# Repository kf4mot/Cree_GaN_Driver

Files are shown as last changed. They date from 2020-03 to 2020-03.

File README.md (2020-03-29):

# Cree GaN Gate Driver and Power Sequencer.
A general purpose GaN gate driver board based on [Cree APPNOTE-011 Rev. B](https://github.com/kf4mot/Cree_GaN_Driver/blob/master/docs/gan_hemt_biasing_circuit_with_temperature_compensation.pdf).
Provides about 2 ms of delay after power is good before switching on the mosfet. Switch off during power fail or shut down is nearly instant.

**Incomplete. Tested with DC load for function and power sequencing only.**

**Things worth knowing**

1. If operating at 14 Volts or less then R10 should be decreased from 4.7KΩ to 1KΩ.
1. C8 value can change per installation, or is optional. A though hole electrolytic soldered to the adjacent power pads is also a convenient option for bulk capacitance.
1. Infineon SPD15P10PL G can be used as a alternate mosfet. **Untested**
1. The series resistance that is R11, R13, and RV1 is there for hackability. Allowing for GaN's with differing gate voltage requirements and to have the ability to use fixed resistors for preventing voltage shift.

[Schematic](https://github.com/kf4mot/Cree_GaN_Driver/blob/master/hardware/Cree_GaN_Driver.pdf)

[Licensed under CERN-OHL-S V2. Julian White, 2020](https://www.ohwr.org/project/cernohl/wikis/home)

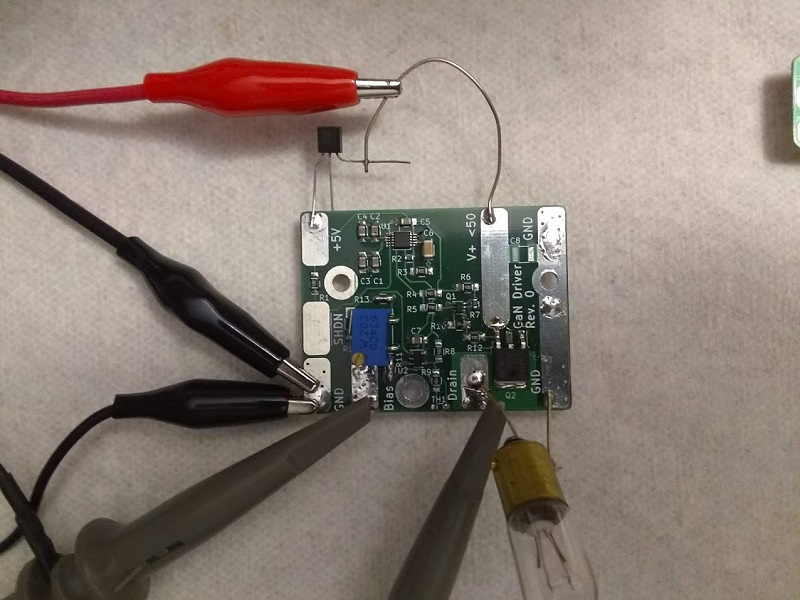
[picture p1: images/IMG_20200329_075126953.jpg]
First! First Board


Ch.1 is drain. Ch.2 is gate.

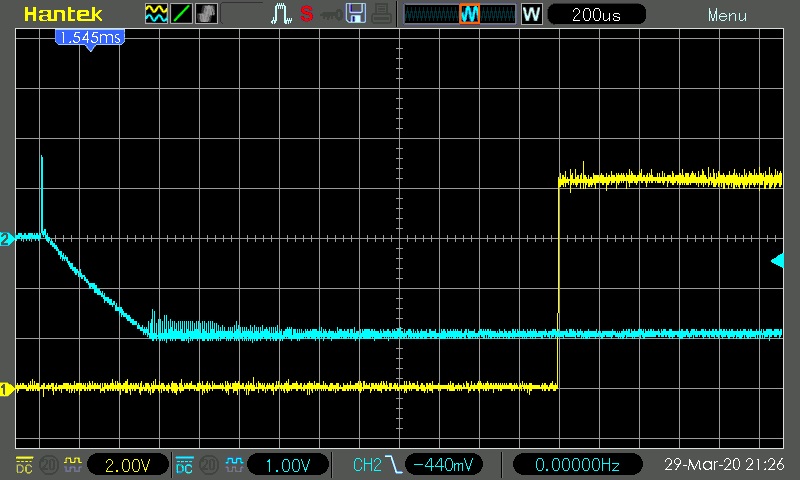
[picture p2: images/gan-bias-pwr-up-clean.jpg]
First! Normal Power Up


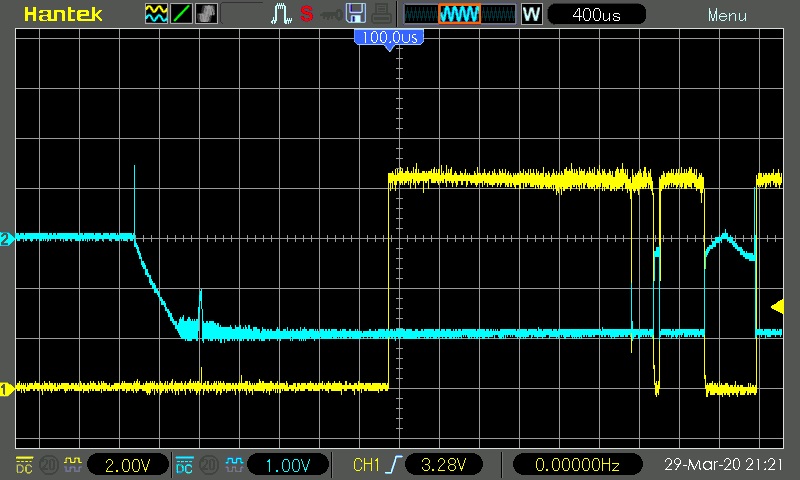
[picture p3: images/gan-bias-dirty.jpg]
First! Power Fail at Power Up


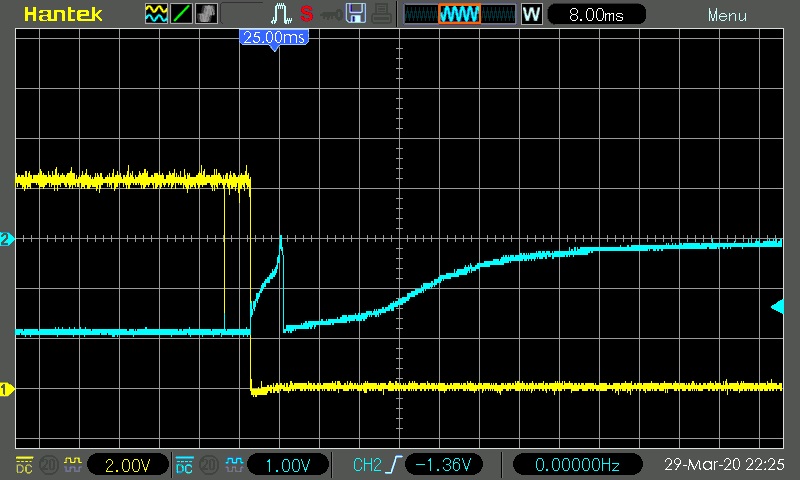
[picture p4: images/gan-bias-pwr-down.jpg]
What does this do? Normal Turn Off


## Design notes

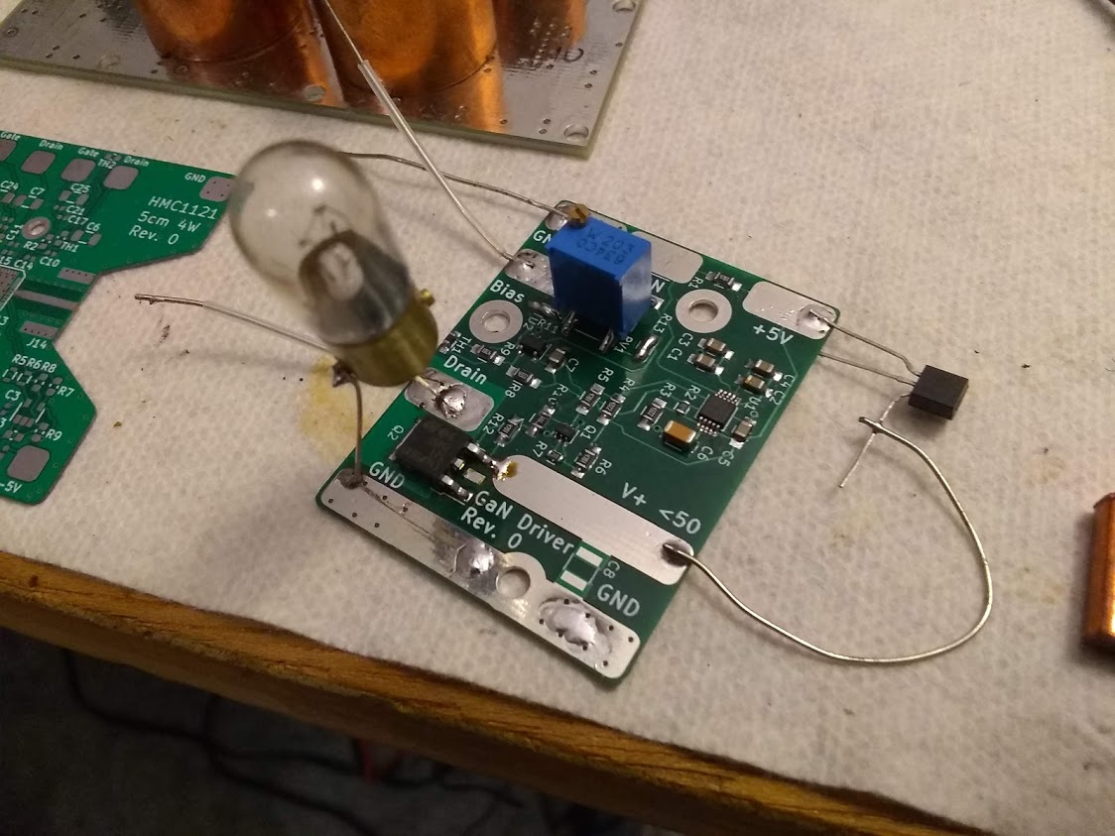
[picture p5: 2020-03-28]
images/first-board.jpg

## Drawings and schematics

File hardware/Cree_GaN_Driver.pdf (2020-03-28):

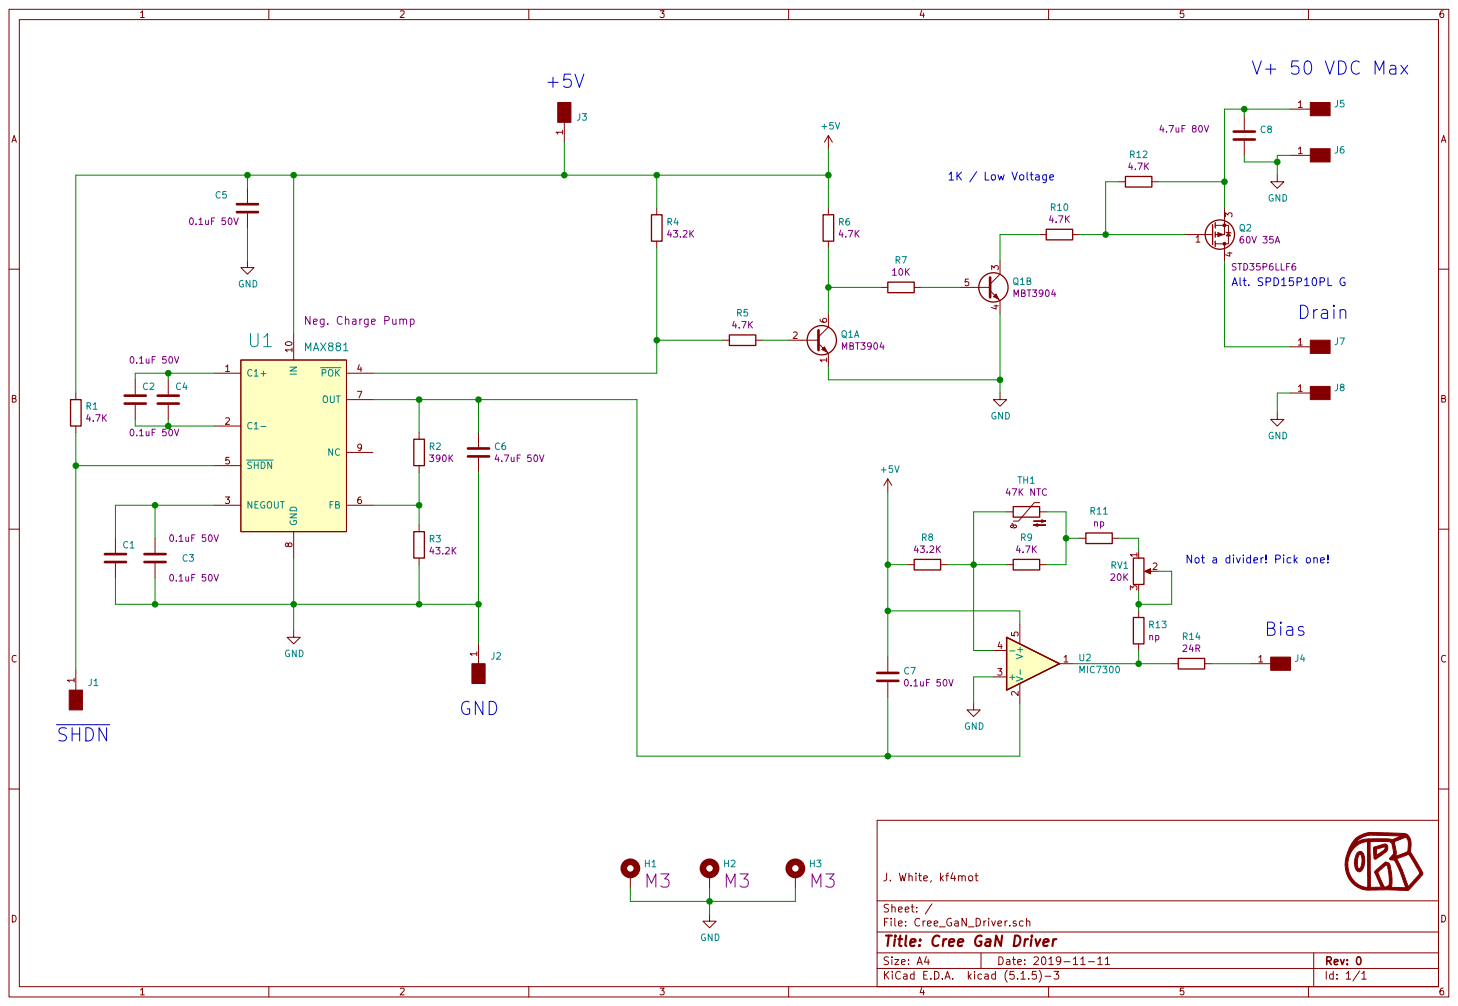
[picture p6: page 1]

8 NC 9 U1 MAX881 Neg. Charge Pump R11

File: Cree_GaN_Driver.sch Sheet: / J. White, kf4mot

Id: 1/1 Title: Cree GaN Driver

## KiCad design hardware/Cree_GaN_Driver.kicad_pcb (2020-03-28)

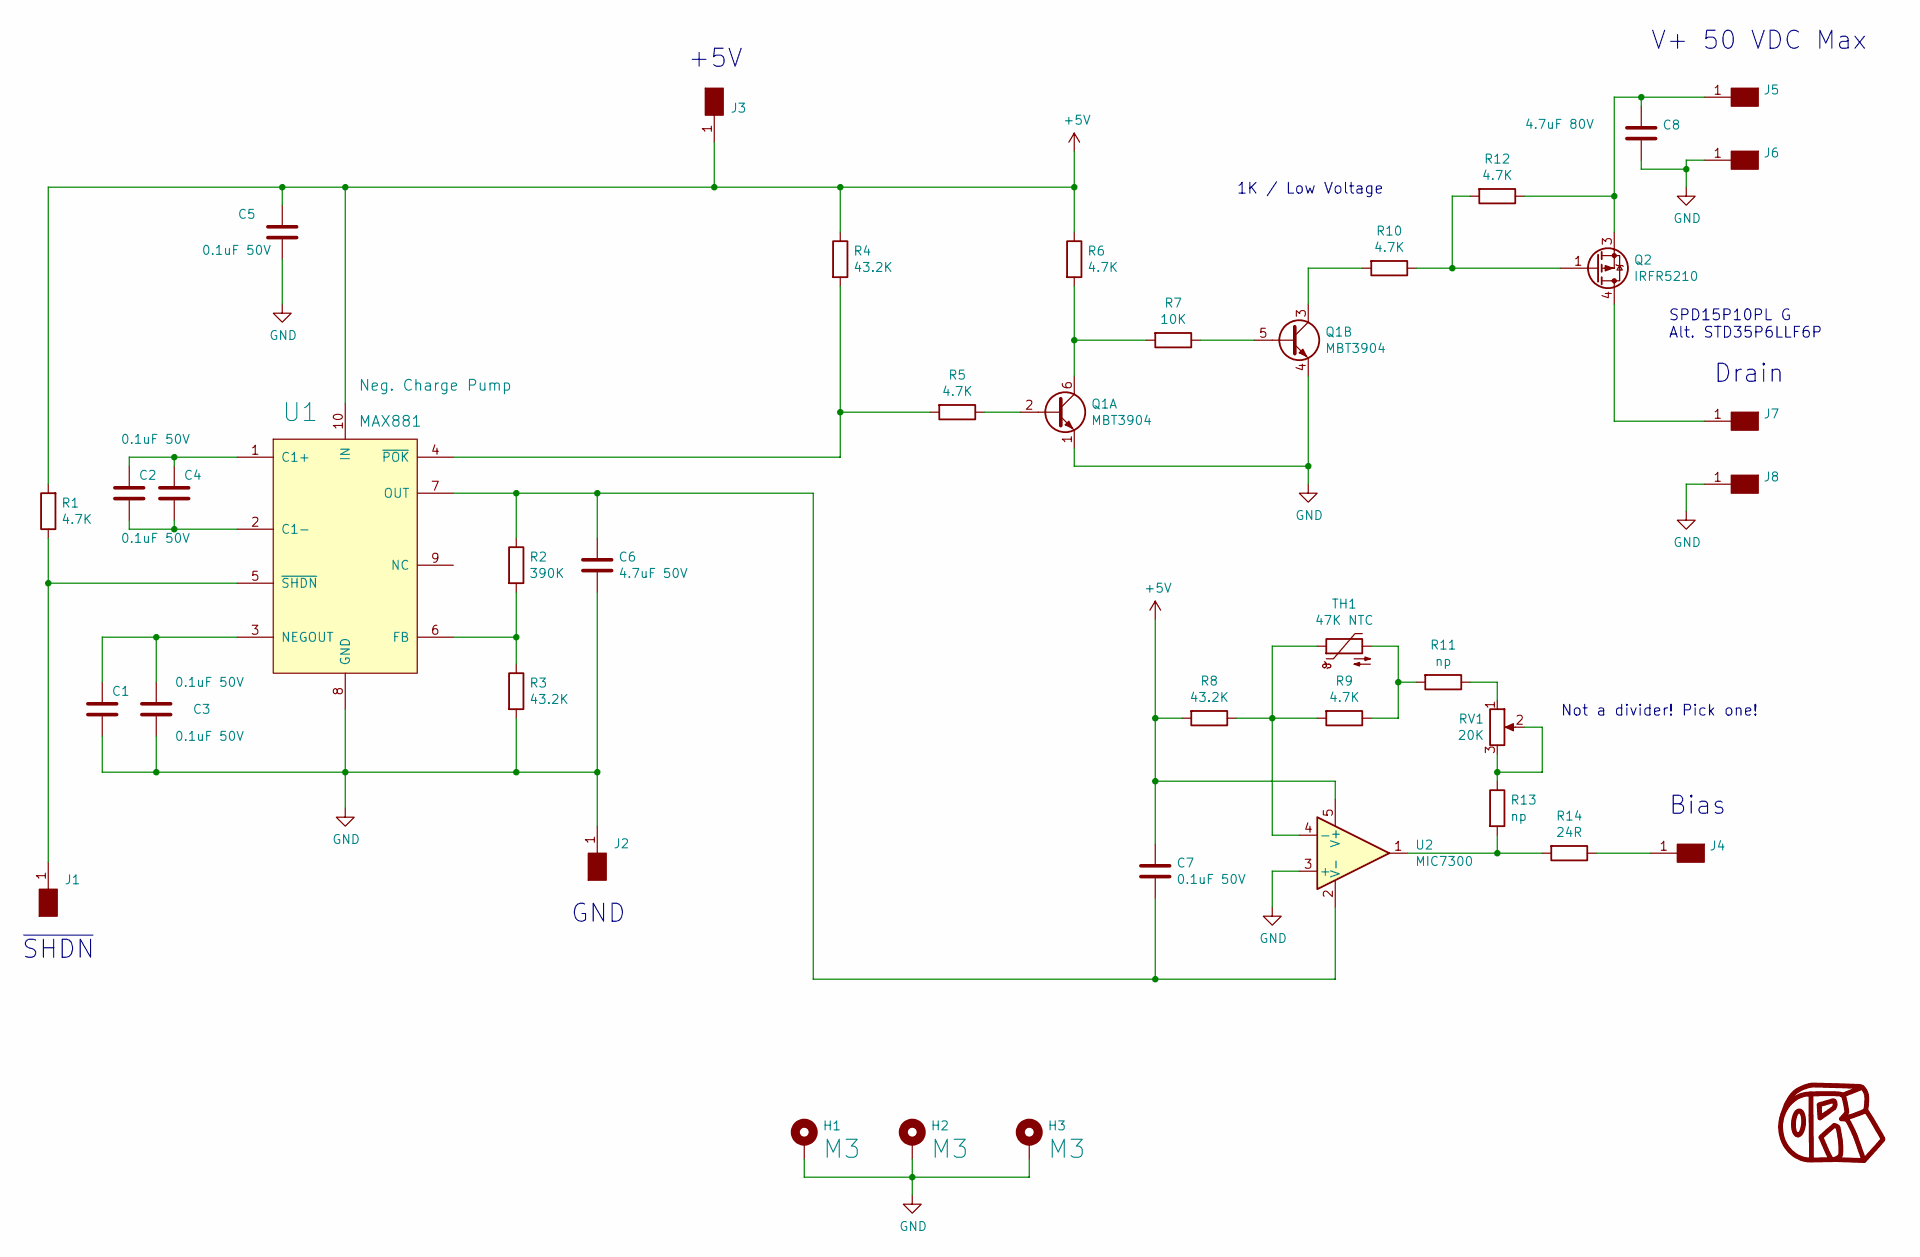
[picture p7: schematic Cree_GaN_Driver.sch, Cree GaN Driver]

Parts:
C1, C2, C3, C4, C5, C7: 0.1uF_50V_0805_x7r; C_0805_HandSoldering; Part Number C0805C104K5RACTU
C6: C_4.7uf_50V_x7r_1206; C_1206; Part Number GRM31CR71H475KA12L
C8: 4.7uf_80V_1210; R_1210; Part Number GRM32ER71K475KE14L
H1, H2, H3: MountingHole_Pad_M3; MountingHole_3.2mm_M3_Pad
J1, J2, J3, J4, J5, J6, J7, J8: Conn_5x10mm_pad; SolderWirePad_single_SMD_5x10mm
Q1: MBT3904; SOT-363_SC-70-6; Part Number MBT3904DW1T1G
Q2: IRFR5210; TO-252-3_TabPin4; Part Number IRF5210STRLPBF
R1, R5, R6, R9, R10, R12: R_4.7k_sm0805; R_0805_HandSoldering; Part Number RC0805FR-074K7L
R2: R_390k_sm0603; R_0603; Part Number RT0603FRE07390KL
R3, R4, R8: R_43.2K_sm0805; R_0805_HandSoldering; Part Number RC0805FR-0743K2L
R7: R_10k_sm0603; R_0603; Part Number RT0603FRE0710KL
R11, R13: R; R_0805_HandSoldering; Part Number np
R14: R_24_sm1206; R_1206_HandSoldering; Part Number CR1206-FX-24R0ELF
RV1: R_POT_20K_84WR20KLFTR; POT_TT84W; Part Number 84WR20KLF
TH1: Thermistor_NTC_ERT-J1VV473J; R_0603_HandSoldering; Part Number ERT-J1VV473J
U1: MAX881; MSOP-10_3x3mm_Pitch0.5mm; Part Number MAX881REUB
U2: MIC7300; SOT-23-5; Part Number MIC7300YM5-TR

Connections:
+5V: C5.1, C7.1, J3.1, R1.2, R4.1, R6.1, R8.2, U1.10 (IN), U2.5 (V+)
GND: C1.2, C3.2, C5.2, C6.2, C8.2, H1.1, H2.1, H3.1, J2.1, J6.1, J8.1, Q1.1 (E1), Q1.4 (E1), R3.2, U1.8 (GND), U2.3 (+)
unnamed: C1.1, C3.1, U1.3 (NEGOUT)
unnamed: C2.1, C4.1, U1.1 (C1+)
unnamed: C2.2, C4.2, U1.2 (C1-)
unnamed: C6.1, C7.2, R2.1, U1.7 (OUT), U2.2 (V-)
unnamed: C8.1, J5.1, Q2.3 (S), R12.1
unnamed: J1.1, R1.1, U1.5 (~SHDN)
unnamed: J4.1, R14.1
unnamed: J7.1, Q2.4 (D)
unnamed: Q1.2 (B1), R5.1
unnamed: Q1.3 (C1), R10.2
unnamed: Q1.5 (B1), R7.1
unnamed: Q1.6 (C1), R6.2, R7.2
unnamed: Q2.1 (G), R10.1, R12.2
unnamed: R2.2, R3.1, U1.6 (FB)
unnamed: R4.2, R5.2, U1.4 (~POK)
unnamed: R8.1, R9.2, TH1.1, U2.4 (-)
unnamed: R11.1, RV1.1
unnamed: R9.1, R11.2, TH1.2
unnamed: R13.1, RV1.2, RV1.3
unnamed: R13.2, R14.2, U2.1

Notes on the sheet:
~SHDN
+5V
V+ 50 VDC Max
Drain
Bias
GND
SPD15P10PL G Alt. STD35P6LLF6P
1K / Low Voltage
Not a divider! Pick one!

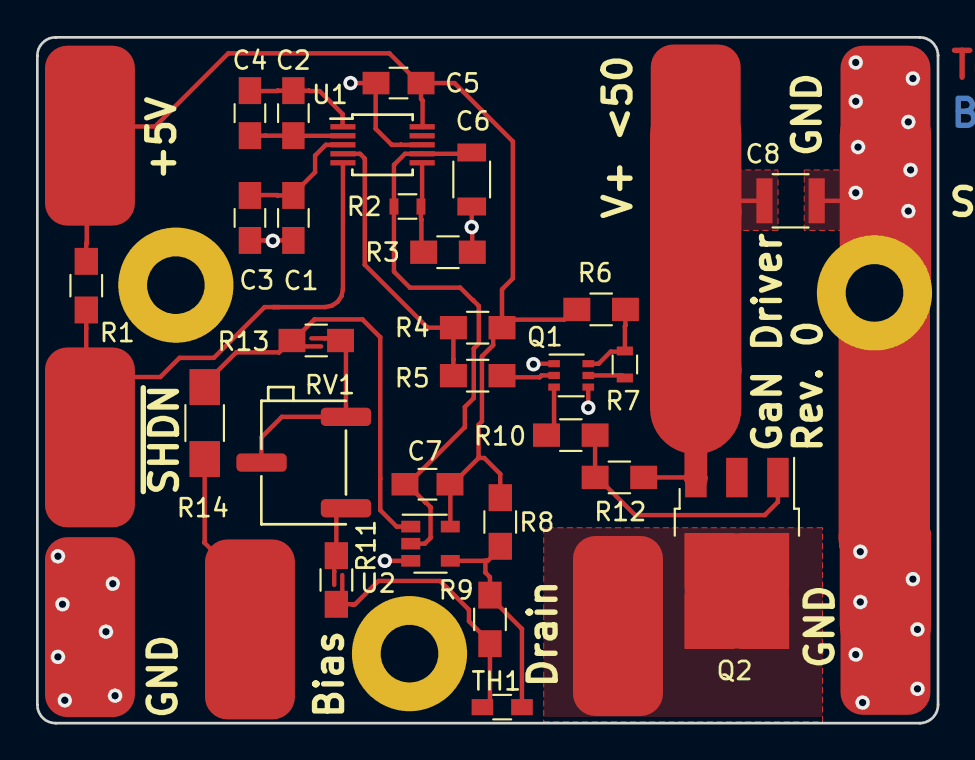
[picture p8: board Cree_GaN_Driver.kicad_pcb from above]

Board: 2 copper layers, 50.0 x 38.1 mm, 39 parts (0 on the bottom side), 22 nets.
